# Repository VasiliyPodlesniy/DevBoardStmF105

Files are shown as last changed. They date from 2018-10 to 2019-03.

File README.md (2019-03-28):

# DevBoardStmF105
Отладочная плата на базе микроконтроллера Stm32F105/107.

Функционал изделия:

- 3 аналоговых буферизированных входа;
- 27 цифровых входов/выходов;
- подключение к CAN-шине;
- задание адреса;
- возможность прошивки через dfu;
- USB-интерфейс;
- обработка сигналов микроконтроллером Stm32F105/107;
- связь с периферийными устройствами по RS232/422/485;
- подключение внешнего источника питания до 40В.

demo image

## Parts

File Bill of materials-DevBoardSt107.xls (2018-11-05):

Comment | Description | Designator | Footprint | LibRef | Quantity
SN65HVD230D | 3,3V CAN TRANSCEIVERS | DA6 | SO8 | SN65HVD23x | 1
DS1040-05 | DIP переключатель | SW1 | DIP5 | Switch 5-pin SMD | 1
Jumper | DIP переключатель | SW2, SW3 | PLS2-2 | Switch 1-pin SMD | 2
LM2940IMP-5.0/NOPB | Low-Dropout Regulator for 5-V to 3.3-V Conversion | DA4 | SOT-223 | LM2940 | 1
LM3940IMP-3.3/NOPB | Low-Dropout Regulator for 5-V to 3.3-V Conversion | DA2 | SOT-223 | LM3940 | 1
BAS516 | Диод | VD1 | SOD523 | Diode | 1
SS14 | Диод Шоттки | VD2, VD4, VD7, VD8, VD9, VD10, VD11 | SMA | DiodeSchottky | 7
USB6B1 | Защита линии данных | VD3 | SO8 | USB6B1 | 1
XXX | Катушка индуктивности | L1 | L0603 | Inductor | 1
8MHz | Кварцевый резонатор | Z1 | QSMD5.0x3.2x1.0 | Crystal | 1
RESET | Кнопка | S1 | DTSM 32 | Button_SMD | 1
0,1мк | Конденсатор | C1, C2, C8, C9, C10, C12, C13, C14, C15, C16, C17, C19, C21, C22, C23, C24, C25 | C0603 | Capacitor | 17
0,47мк | Конденсатор | C4, C6 | C0603 | Capacitor | 2
22 | Конденсатор | C11, C18 | C0603 | Capacitor | 2
22мк | Конденсатор | C7 | C1210 | Capacitor | 1
33мк | Конденсатор | C5 | C1210 | Capacitor | 1
10мк | Конденсатор полярный | C3, C20 | TANTAL CASE B | Capacitor_pol | 2
STM32F107RCT6 | Микроконтроллер 64-pin | DD1 | LQFP64 | STM32F107RCT6 | 1
LMV358IDR | Операционный усилитель ±6В | DA1, DA3, DA5 | SO8 | LMV358IDR | 3
Jumper | Переключатель адреса | SW4, SW5 | PLS2-4 | Switch 2-pin SMD | 2
MF-MSMF050 | Предохранитель | FU1 | FUSE812 | Fuse | 1
MF-MSMF075 | Предохранитель | FU2 | FUSE812 | Fuse | 1
CAN | Разъем - 2 конт. розетка | X6 | TERMINAL 3 way-2.54mm | Header_3_sct | 1
SWD | Разъем - 5 конт. розетка | X3 | PLS2-6 | Header_6_sct | 1
Transiever RS | Разъем - 5 конт. розетка | X7 | TERMINAL 6 way-2.54mm | Header_6_sct | 1
USB | Разъем - 5 конт. розетка | X2 | USB-B Micro | Header_6_sct | 1
ADC Inputs | Разъем - 8 конт. розетка | X1 | PLS-8 | Header_8_sct | 1
Left-stand connectors | Разъем - 20 конт. розетка | X4 | PLS-20-2 | Header_20 | 1
Right-stand connectors | Разъем - 20 конт. розетка | X5 | PLS-20-2 | Header_20 | 1
0 | Резистор | R1, R2, R9, R10 | R0603 | Resistor_0,05Вт | 4
1,5к | Резистор | R3 | R0603 | Resistor_0,05Вт | 1
100 | Резистор | R4, R5 | R0603 | Resistor_0,05Вт | 2
120 | Резистор | R19 | R0603 | Resistor_0,05Вт | 1
22 | Резистор | R6, R8 | R0603 | Resistor_0,05Вт | 2
47 | Резистор | R11, R12, R20, R21, R23, R24, R25, R26 | R0603 | Resistor_0,05Вт | 8
47к | Резистор | R7, R13, R14, R15, R16, R17, R18, R22, R27, R28, R29, R30, R31 | R0603 | Resistor_0,05Вт | 13
BL-LS0805UHR | Светодиод | VD5, VD6 | D0805 | LED_L | 2
MAX3160CAP | райвер приемопередатчика RS232/RS422/RS485 | DA7 | SSOP20 | MAX3160 | 1

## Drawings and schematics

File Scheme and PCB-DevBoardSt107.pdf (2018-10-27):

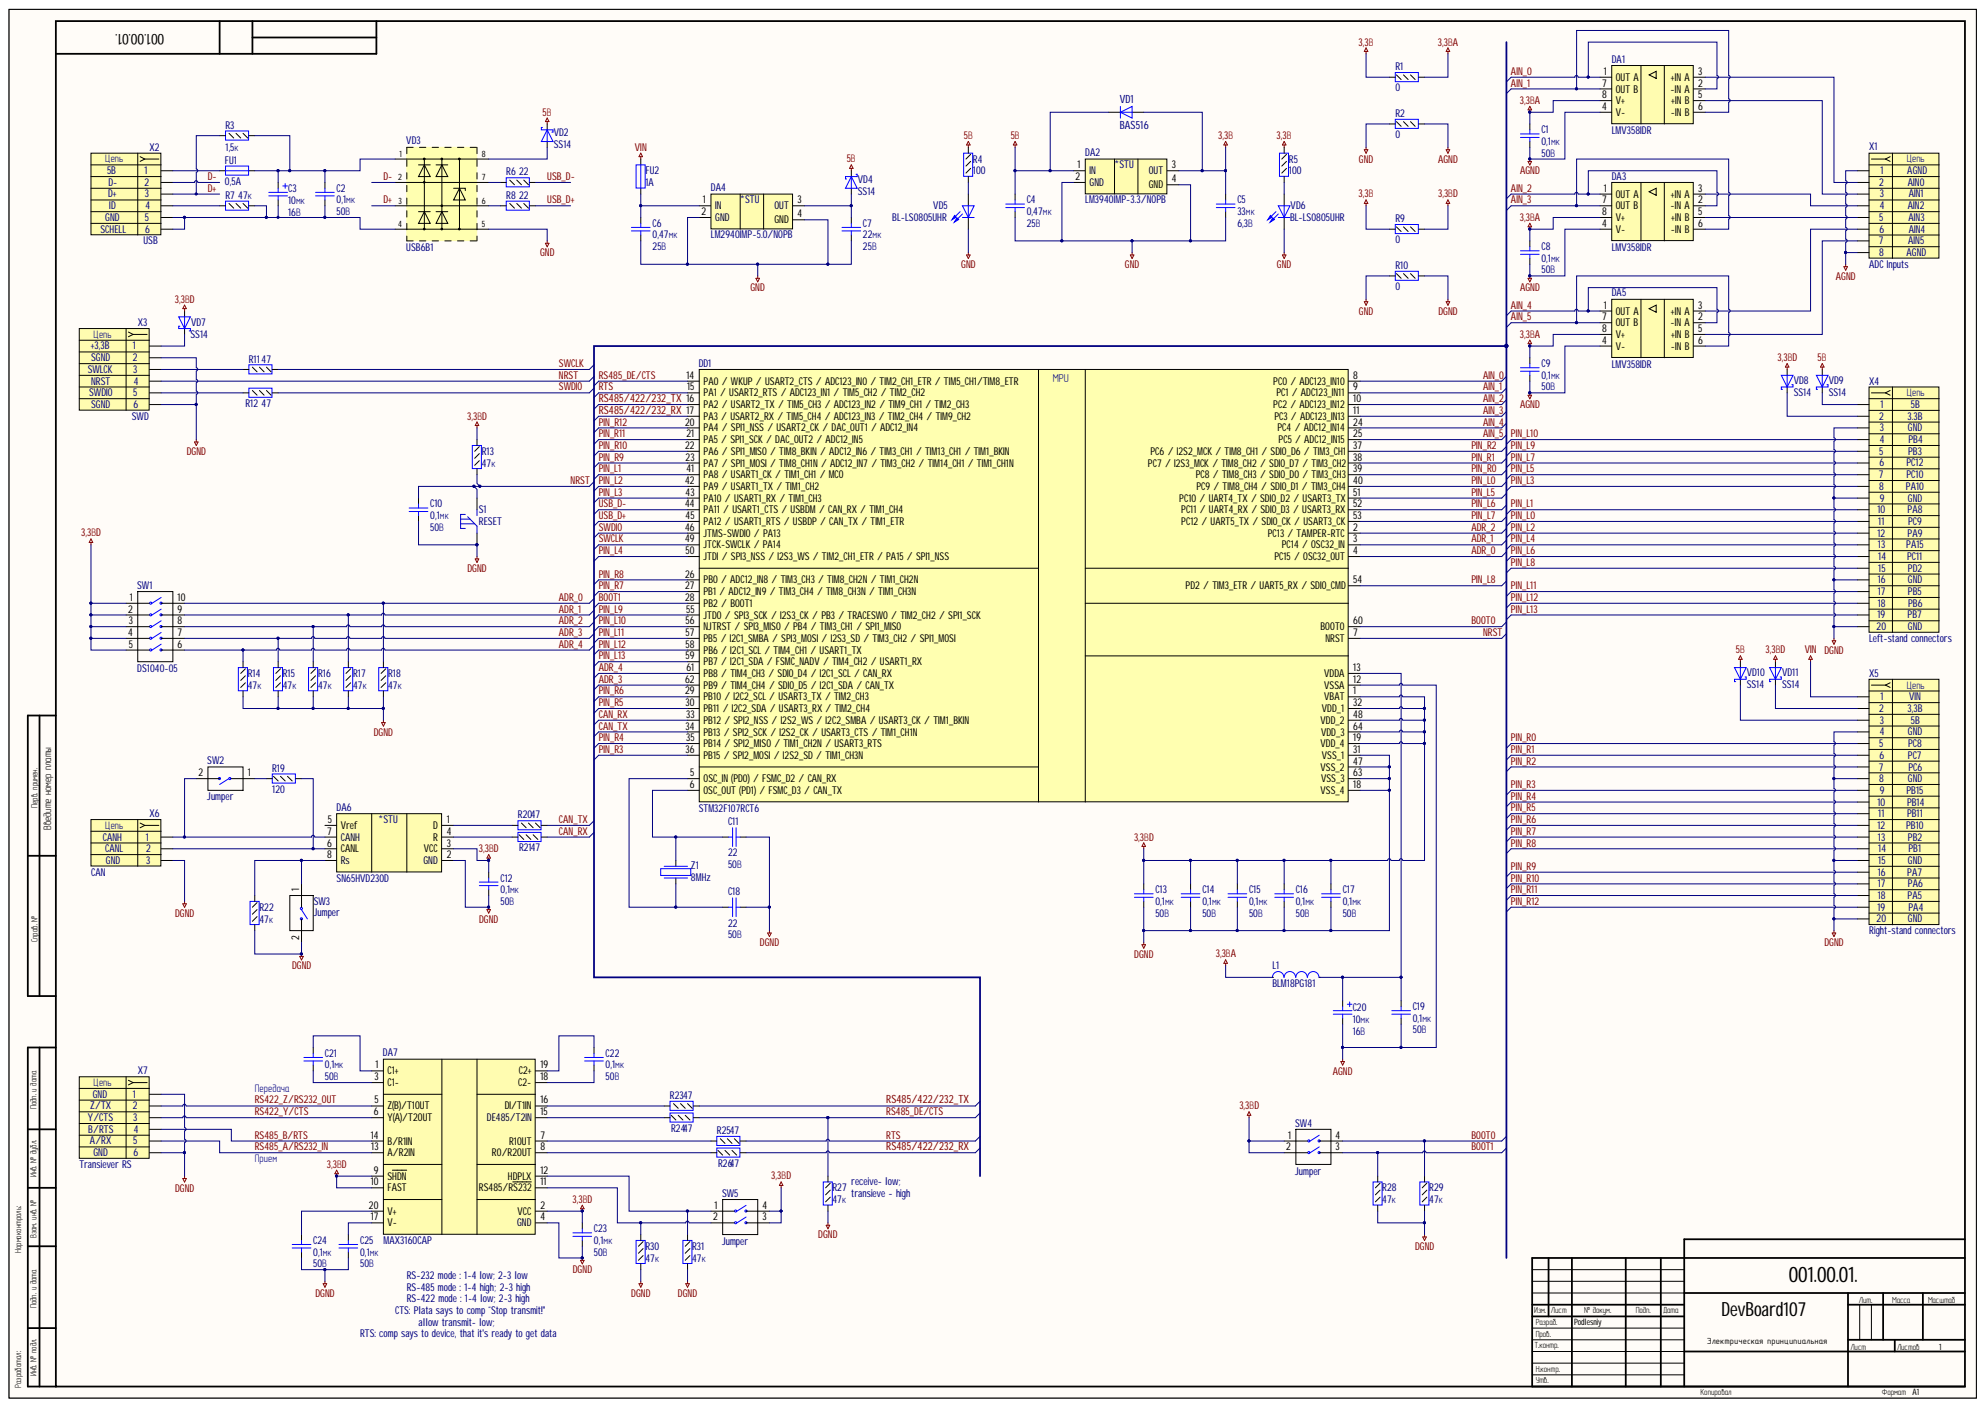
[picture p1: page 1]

AIN_1 | | -IN A | 2 OUT B 7

BAS516

C8 0,1мк 50В | LMV358IDR | 7 | AIN5

8 | AGND

4 | 7 | ADR_3 | PIN_L11 | PB5 / I2C1_SMBA / SPI3_MOSI / I2S3_SD / TIM3_CH2 / SPI1_MOSI 57 | | NRST
5 | 6 | | ADR_4 | PIN_L12 | PB6 / I2C1_SCL / TIM4_CH1 / USART1_TX 58

Инв. № подл. Инв. № дубл. Подп. и дата Взам. инв. № Подп. и дата Перв. примен. Справ. №

PIN_R5 | 10 | PB14

PIN_R10 | 17 | PA6
PIN_R11 | 18 | PA5

Z/TX | 2 | RS422_Y/CTS | Y(A)/T2OUT 6 | RS485_DE/CTS
Y/CTS B/RTS | 3 4 | RS485_B/RTS | B/R1IN 14 | R2447 R2547 | RTS

SHDN 9 | | RS485/RS232
FAST 10 | 11

RS-232 mode : 1-4 low; 2-3 low
RS-485 mode : 1-4 high; 2-3 high
RS-422 mode : 1-4 low; 2-3 high
CTS: Plata says to comp “Stop transmit!"
allow transmit- low;

Изм. | Лист | № докум. | Подп. | Дата
Разраб. | | Podlesniy
Пров.
Т.контр.

RTS: comp says to device, that it's ready to get data

Н.контр.

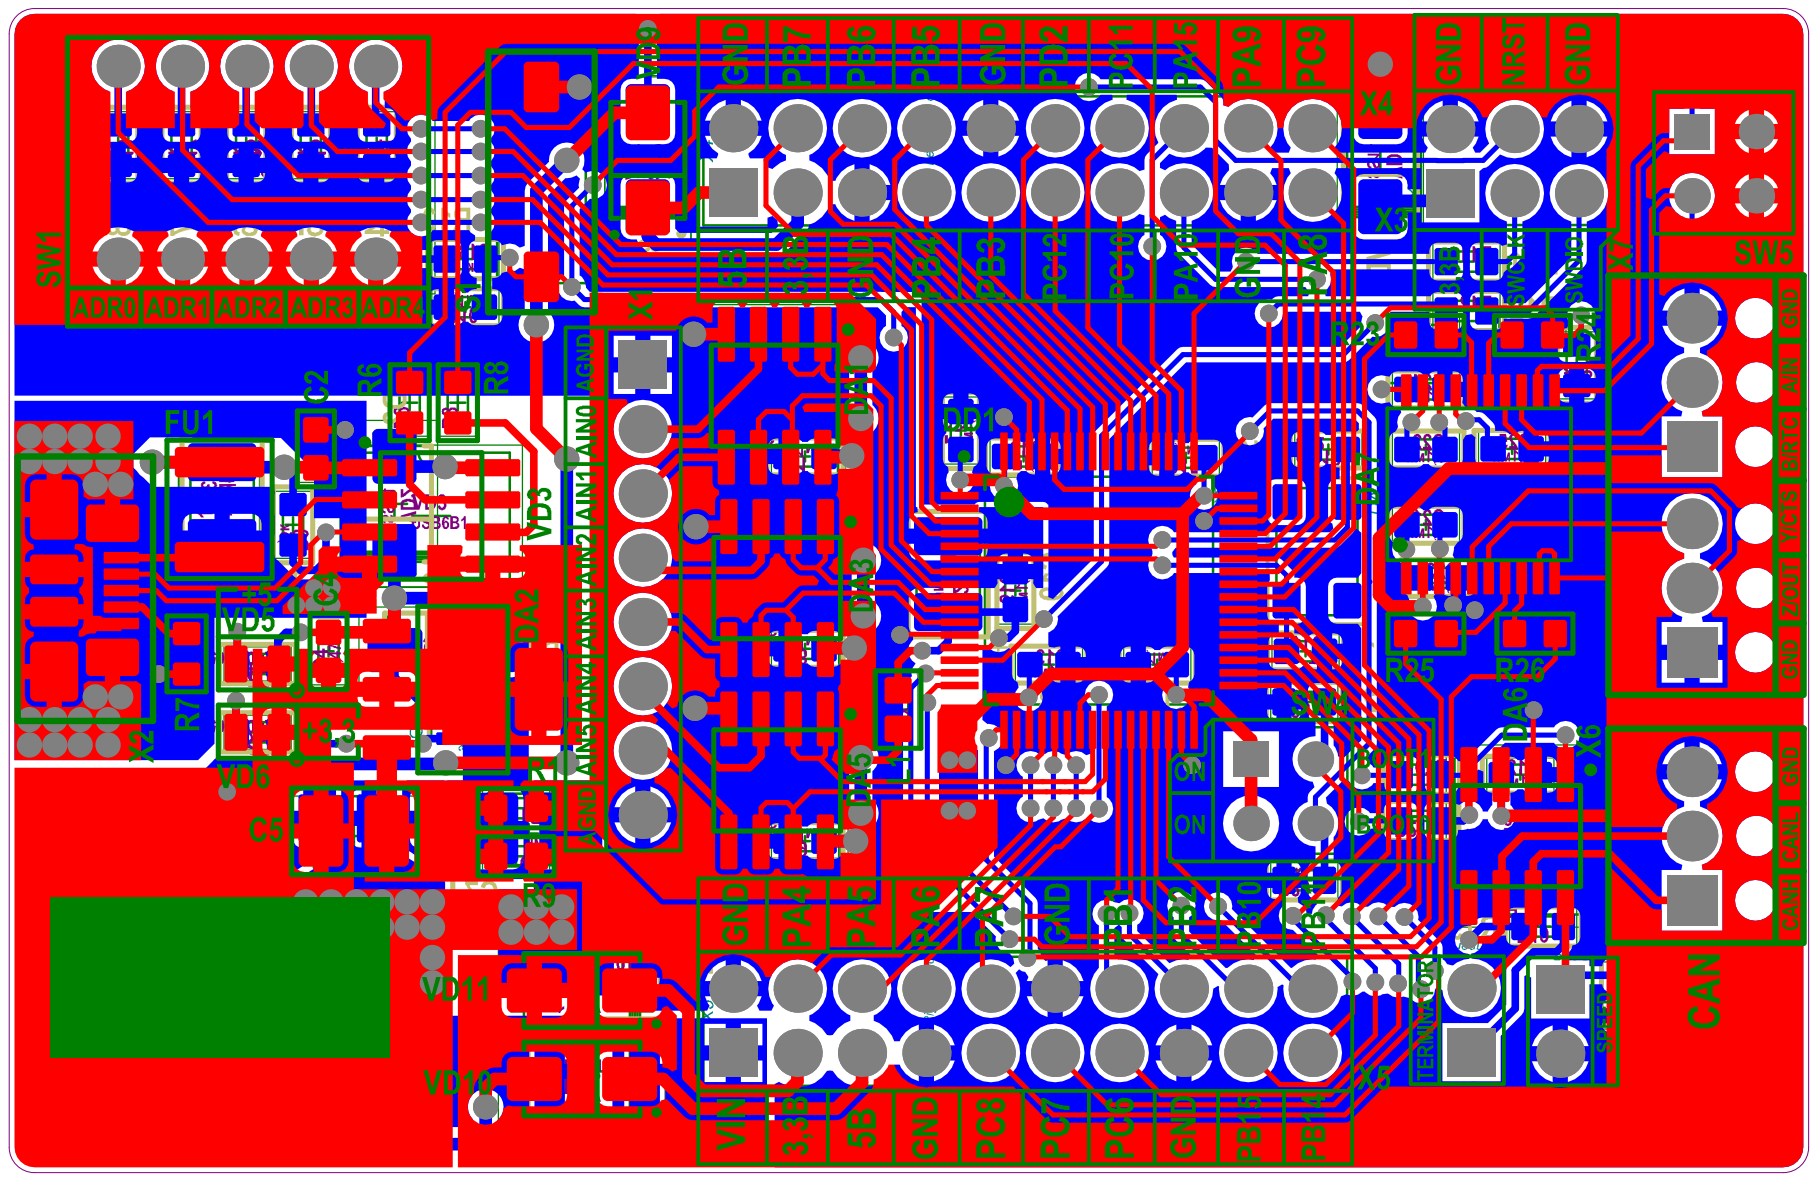
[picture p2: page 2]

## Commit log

2018-10-27 Fisrt Add
    [Bill of materials-DevBoardSt107.xls, DevBoardSt107.PrjPcb, DevBoardSt107.SchDoc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]
2018-11-05 First Add
    [Bill of materials-DevBoardSt107.xls, DevBoardSt107.PrjPcb, DevBoardSt107.SchDoc]
